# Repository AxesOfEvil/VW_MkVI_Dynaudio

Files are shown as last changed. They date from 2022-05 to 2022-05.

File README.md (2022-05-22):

# Dynaudio Amplifier control for VW MkVI GTI

The MkVI Volkswagen GTI uses CAN bus commands to power on/off as well as
for fade/balance settings

This means that an aftermarket head-unit may not be able to power-on the
amplifier, and thus no sound will be heard.

This project addresses this issue by sending the appropriate power on/off 
commands to the Stock Dynaudio amplifier when the 'Amp Power' wire has
12V on it (alternately, attach the common 'Accessory' wire if the head-unit
has no 'Amp Power' wire)

# How it works
The cirucit uses a self-latching power circuit for low-power operation.
When 12V is detected on the 'Amp Power' wire, the circuit will power up.
The Arduino will then keep the circuit powered even if 'Amp Power' is turned
off.

When the Arduino detects the 'Amp Power' at 12V, it will send the Dynaudio
amplifier the power up signals via the CAN bus, and go to sleep.

When the 'Amp Power' wire drops to 0V, the Arduino will wakeup, send the
power-down sequence to the Dynaudio amplifier, and then turn itself off.
Once off, the only way to power up the Arduino again is to apply 12V to the
'Amp Power' wire.

# About the schematic
An AVR based arduino is used because of its 5V tolerance. Specifically,
either a 'Pro Micro' or 'Pro Mini' Arduino is recommended.  It should not
matter if the Arduino board is a 5V or 3.3V variant (both are capable of being
powered at 5V).

The LDO can be replaced with a DC/DC supply to further reduce current, though
the difference is only ~100mW of power (when active, the circuit consumes
negligible power when the 'Power Amp' wire is inactive)

I prefered to use an Arduino 'Pro Micro' instead of the 'Pro Mini' primarily
because it has a USB interface that could be used in the future to control
additional CAN bus functions.  However, the 'Pro Micro' uses USB programming
which does not play very nicely with the low-power states used by software.
When using a 'Pro Micro' it is recommended, to flash the 'Optiboot' firmware
such that the board can be programmed via Serial1 instead of via USB.

# Building the software
The software uses the following Arduino libraries:

* `Arduino-MCP2515` : https://github.com/autowp/arduino-mcp2515
* `Low Power`

# CAN bus protocol
The Dynaudio amplifier listens on interface 0x6C7 for amplifier commands.
As the commands were snooped from a working head-unit, their individual
function is not fully known.

Power up seems to require a minimum of 5 frames, with the 1st byte being
0x1B or 0x2B.  After power-on, and additional 13 frames are sent to set the
fade/balance/etc settings, but the meaning of these frames is not yet known.

Power-down requires only a single frame (with 1st byte = 0x2b)

# VW Media Can bys data (100kbps)

| Identifier | Data | Description |
| ---| --- | --- |
| 0x5C1 | 06 00 00 60 | vol up (repeats periodically while button is held) |
| 0x5C1 | 07 00 00 60 | vol down (repeats periodically while button is held) |
| 0x5C1 | 03 00 00 60 | left button (repeats periodically while button is held) |
| 0x5C1 | 02 00 00 60 | right button (repeats periodically while button is held) |
| 0x5C1 | 2A 00 00 60 | mic button (repeats periodically while button is held) |
| 0x5C1 | 1A 00 00 60 | phone button (repeats periodically while button is held) |
| 0x5C1 | 29 00 00 60 | return button (repeats periodically while button is held) |
| ---------- | ----------------------- | ----------- |
| 0x6C7 | 80 04 2B 57 00 05 01 xx | Dynaudio amp left/right fade (8-bit signed int. 0x80 = full left, 0x7f = full right |
| 0x6C7 | 80 04 2B 58 00 05 01 xx | Dynaudio amp front/back balance (8-bit signed int. 0x80 = full back, 0x7f = full front |
| 0x6C7 | 2B 50 00 | Dynaudio amp power down |
| 0x6C7 | 1B 42 | Dynaudio amp ??? (powerup frame 1) |
| 0x6C7 | 1B 43 | Dynaudio amp ??? (powerup frame 2) |
| 0x6C7 | 1B 41 | Dynaudio amp ??? (powerup frame 3) |
| 0x6C7 | 2B 50 01 | Dynaudio amp ??? (powerup frame 4) - power up ? |
| 0x6C7 | 2B 53 00 | Dynaudio amp ??? (powerup frame 5) |
| 0x6C7 | 80 07 2B 55 78 00 00 00 | Dynaudio amp ??? (powerup frame 6) - resent periodically |
| 0x6C7 | C0 22 22 00 | Dynaudio amp ??? (powerup frame 7) - resent periodically |
| 0x6C7 | 80 07 2B 51 00 00 04 05 | Dynaudio amp ??? (powerup frame 8) |
| 0x6C7 | C0 0A 08 FF | Dynaudio amp ??? (powerup frame 9) |
| 0x6C7 | 80 03 1B 52 00 00 0D | Dynaudio amp ??? (powerup frame 10) |
| 0x6C7 | 80 03 1B 54 00 00 0D | Dynaudio amp ??? (powerup frame 11) |
| 0x6C7 | 80 03 1B 57 00 00 0D | Dynaudio amp ??? (powerup frame 12) |
| 0x6C7 | 80 03 1B 58 00 00 0D | Dynaudio amp ??? (powerup frame 13) |
| 0x6C7 | 80 03 1B 59 00 00 0D | Dynaudio amp ??? (powerup frame 14) |
| 0x6C7 | 80 03 1B 5A 00 00 0D | Dynaudio amp ??? (powerup frame 15) |
| 0x6C7 | 80 03 1B 5B 00 00 0D | Dynaudio amp ??? (powerup frame 16) |
| 0x6C7 | 80 03 1B 5C 00 00 04 | Dynaudio amp ??? (powerup frame 17) |
| 0x6C7 | 80 03 1B 5E 00 00 04 | Dynaudio amp ??? (powerup frame 18) |
| ---------- | ----------------------- | The following data was collected by hugovw1976 (see link below) |
| 0x2C3 | aa | aa: bit0 power on |
| 0x635 | aa bb cc | aa: bit0 lights on |
| 0x466 | aa bb cc dd ee ff gg hh | bb: door-open - bit0: driver, bit1: passenger, bit2: rear-driver, bit3: rear passenger, bit4: hood, bit5: trunk |
| 0x35B | aa bb cc dd ee ff gg hh | ccbb: RPM*4 (unconfirmed) |
| 0x527 | aa bb cc dd ee ff gg hh | ccbb: Speed (units?) (unconfirmed), ff: (outside temperature(C) +50)/2 |
| 0x621 | aa bb cc dd ee ff gg | aa: bit 2: wiper state, dd: fuel level (liters) (bit 7 is set to indicate low-fuel when <10l) |
| 0x65D | aa bb cc dd ee ff gg hh | ddeecc: odometer (unconfirmed) |
| 0x351 | aa bb cc dd ee ff gg hh | aa: bit0: reverse (unconfirmed), cc: bit0: brake (unconfirmed)|
| 0x571 | aa bb cc dd ee ff | aa: (battery voltage * 10 + 50) / 2 |
| 0x151 | aa bb cc dd | bb: seat-belt (unconfirmed) |

# Additional Resources
* Using a Raspberry Pi to snoop the CAN bus with a $3 Ebay MCP2515
  * This modification allows running the SPI interface at 3.3V while running
    the CAN interface at 5V: https://forums.raspberrypi.com/viewtopic.php?t=141052
  * Savvy CANbus GUI: https://www.savvycan.com/

* Pinout for VW MkBI head unit
  * https://pinoutguide.com/Car-Stereo-Volkswagen-Porsche/Volkswagen_RCD_310_Head_U_pinout.shtml
  * https://connector.pinoutguide.com/40__16_12_12__pin_Head_Unit_Car_Stereo_Quadlock/

* Interesting articles on CAN bus hacking
  * General overview: https://theksmith.com/software/hack-vehicle-bus-cheap-easy-part-2/
  * Analyzing a VW Gauge cluster using CAN bus hacking (also shows how to use
    the 'savvy' CAN bus analyzer GUI: https://www.youtube.com/watch?v=GOuglqFtmOE&t=23s
  * CANid database for various vendors: https://github.com/iDoka/awesome-automotive-can-id
  * DTB files for CANids for various vendors: https://github.com/commaai/opendbc
  * XDA posting by hugovw1976 with some Golf6 Canids: https://forum.xda-developers.com/t/mtcd-kgl-px5-canbus-problem-with-vw-golf-6.3632690/post-73939457

* Installing Optiboot on Pro Micro
  * NOTE: The official Optiboot github repo supports the Atmega32U4 now.
    https://www.instructables.com/How-to-upload-sketches-to-Pro-MicroLeonardo-via-se/
  * Optiboot home: https://github.com/Optiboot/optiboot/wiki

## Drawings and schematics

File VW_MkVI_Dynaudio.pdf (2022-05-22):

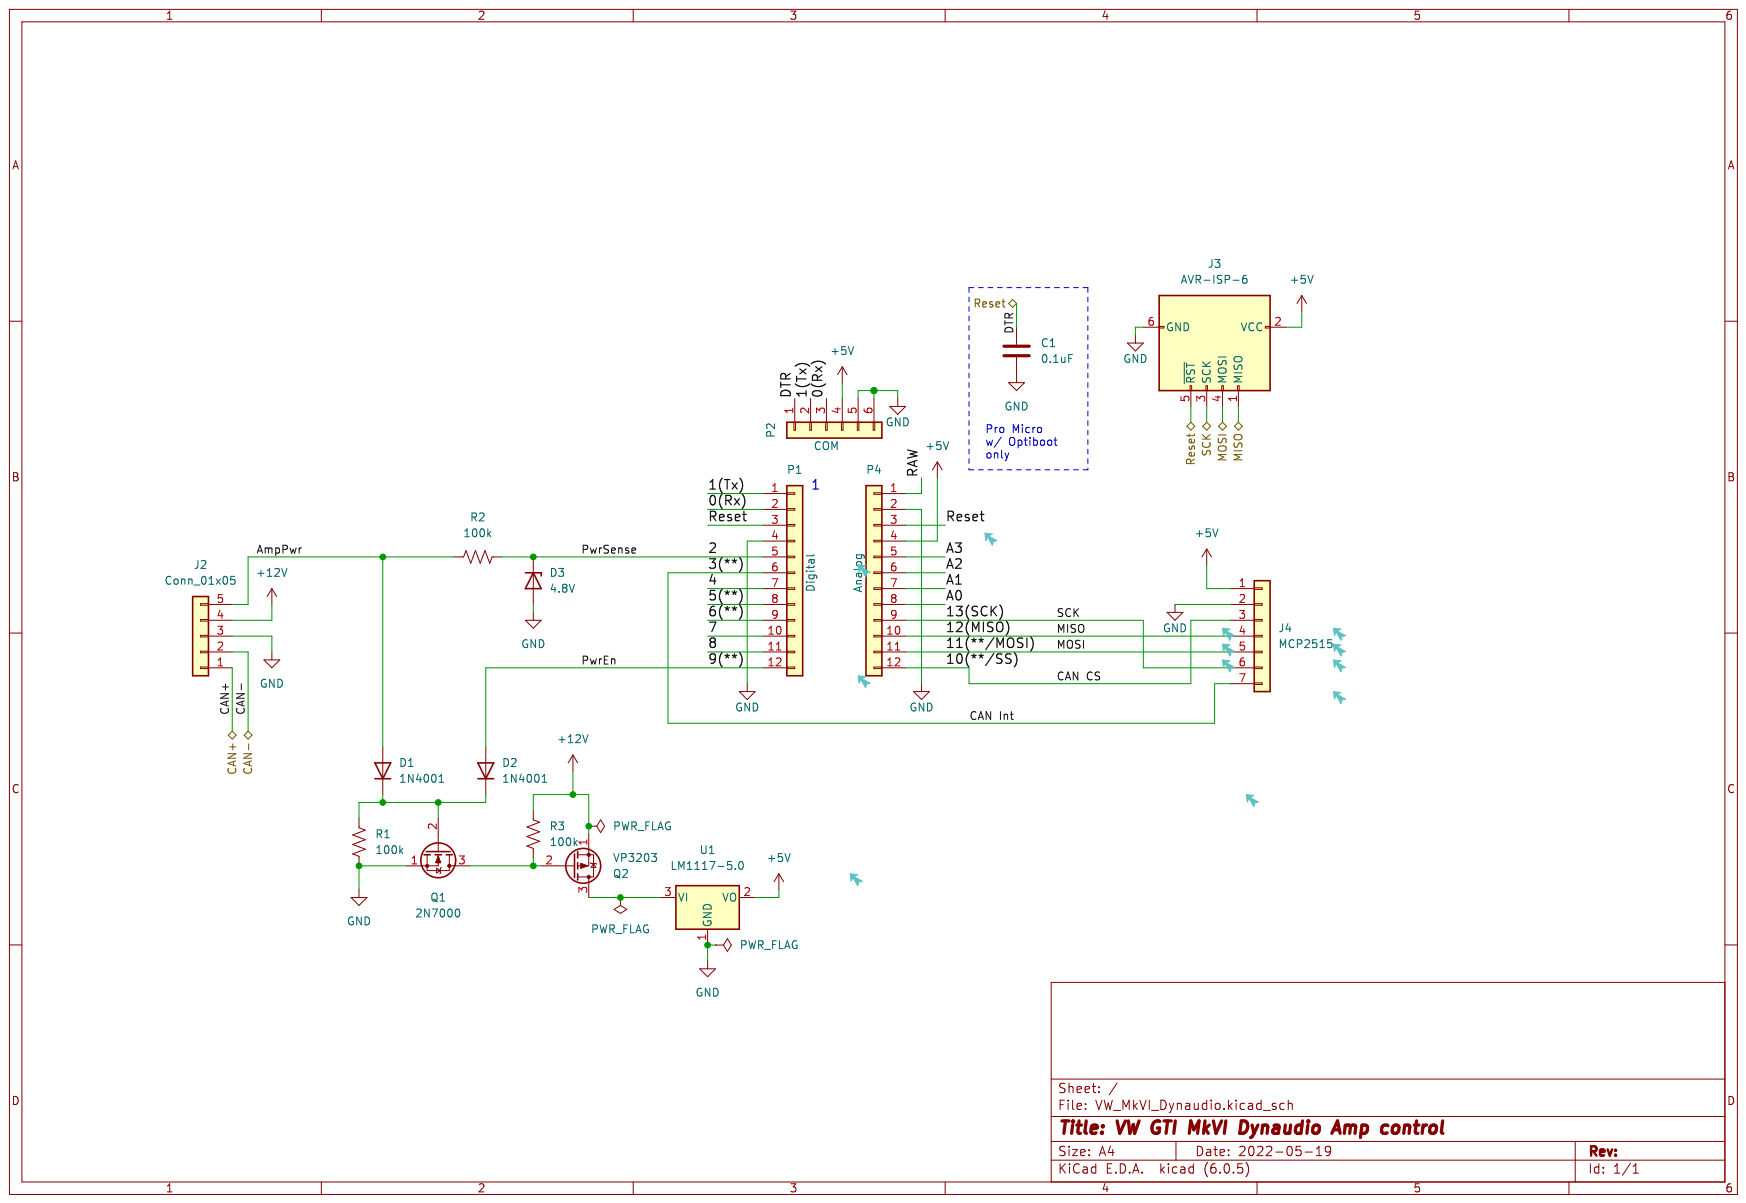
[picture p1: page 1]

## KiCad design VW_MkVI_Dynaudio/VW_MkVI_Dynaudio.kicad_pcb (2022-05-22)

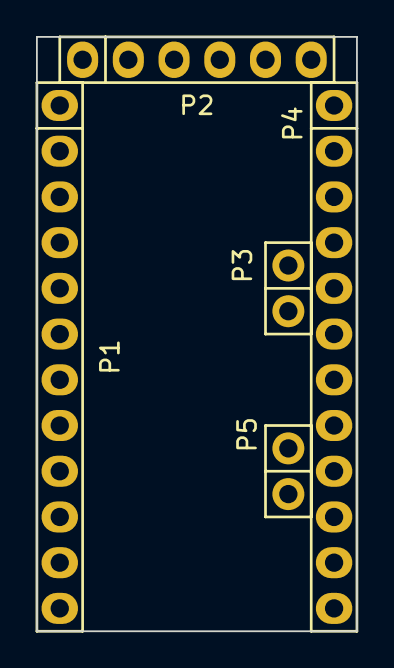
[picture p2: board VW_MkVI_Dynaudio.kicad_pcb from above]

Board: 2 copper layers, 17.8 x 33.0 mm, 5 parts (0 on the bottom side), 5 nets, no tracks yet.

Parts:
P1: Digital; Socket_Strip_Arduino_1x12
P2: COM; Socket_Strip_Arduino_1x06
P3, P5: ADC; Socket_Strip_Arduino_1x02
P4: Analog; Socket_Strip_Arduino_1x12

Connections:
/0(Rx): P1.2, P2.3
/1(Tx): P1.1, P2.2
/Reset: P1.3, P4.3
GND: P1.4, P2.5, P2.6, P4.2
VCC: P2.4, P4.4

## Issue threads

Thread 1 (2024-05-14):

Trying to simulate ignition

veso266, 2024-05-14:
Hello there
I have a test bench for PQ platform which you can see on the picture: https://imgur.com/fyGPqXu

On my Bench is RNS510 and 3C0 907 530 L gateway module

I would like to simulate ignition message
I use MCP2515 module with my Arduino (seerduino the only difference is that u can also put it on 3.3V operation instead of 5V)

I also discovered that VW PQ cars have 3 canbuses: https://imgur.com/a/FAXZZzY
Infotaiment - 100kbps
Conveniences - 100kbps
Drive train - 500kbps

I was able to throw together this little test program to trying to simulate ignition message
I tried to use this library: https://github.com/autowp/arduino-mcp2515/tree/master
```c
#include <SPI.h>
#include "mcp25151.h"

//MCP_CAN CAN0(10);     // Set CS to pin 10
MCP2515 mcp2515(10); // Set CS to pin 10

struct can_frame canMsg;

void sendCAN(uint32_t id, uint8_t length, uint8_t data0 = 0x00 , uint8_t data1 = 0x00 , uint8_t data2 = 0x00 , uint8_t data3 = 0x00 , uint8_t data4 = 0x00 , uint8_t data5 = 0x00 , uint8_t data6 = 0x00 , uint8_t data7 = 0x00);

void setup() {
  Serial.begin(115200);

  // Initialize MCP2515 running at 8MHz with a baudrate of 100kb/s and the masks and filters disabled.
  //if(CAN0.begin(MCP_ANY, CAN_500KBPS, MCP_8MHZ) == CAN_OK) Serial.println("MCP2515 Initialized Successfully!");
  //else Serial.println("Error Initializing MCP2515...");

  //CAN0.setMode(MCP_NORMAL);   // Change to normal mode to allow messages to be transmitted

  Serial.println("SetBitrate: " + String(mcp2515.setBitrate(CAN_500KBPS, MCP_8MHZ)));
  Serial.println("SetMode: " + String(mcp2515.setNormalMode()));
  Serial.println("VW CAN Interface");

}

void loop() {
  sendCAN(0x271, 2, 0x01, 0x80); //Ignition on

  //3 bytes 1. byte hat 0 wenn licht aus und 0x5C wenn licht an
  sendCAN(0x635, 3, 0x00, 0xFF, 0x00); //Light on

//7 bytes 1st byte bit 1 reverse gear
  //sendCAN(0x351, 7, 0x00, 0x01, 0x00, 0x02, 0x00, 0x00, 0x7E, 0x7E); //Car is in reverse

  delay(100);

}

void sendCAN(uint32_t id, uint8_t length, uint8_t data0 , uint8_t data1 , uint8_t data2 , uint8_t data3 , uint8_t data4 , uint8_t data5 , uint8_t data6 , uint8_t data7) {
  struct can_frame canMsg1;
  canMsg1.can_id  = id;
  canMsg1.can_dlc = length;
  canMsg1.data[0] = data0;
  canMsg1.data[1] = data1;
  canMsg1.data[2] = data2;
  canMsg1.data[3] = data3;
  canMsg1.data[4] = data4;
  canMsg1.data[5] = data5;
  canMsg1.data[6] = data6;
  canMsg1.data[7] = data7;
  mcp2515.sendMessage(MCP2515::TXB1, &canMsg1);
}

The problem is that nothing happens
If I disconnect the gateway, connect to 100kbps inforaiment bus according to this gateway pinout
```
1,2 - +12v (connection 30)
14 - +12v (connection 15 [Ignition])
11,12 - Ground connection
6 - powertrain CAN bus, low
16 - powertrain CAN bus, high
9 - DIAGNOSE can low
19 - DIAGNOSE can high
8 - Dashboard can low
18 - Dashboard can high
5 - convenience CAN bus, low
15 - convenience CAN bus, high
10 - infotainment CAN bus, low
20 - infotainment CAN bus, high
13 - to Dashboard pin15
```

my radio (RNS510 is not happy: https://imgur.com/B4BlY3l)
if gateway is connected, this is what RNS510 displays: https://imgur.com/PAH2PBI

The problem is that I have no acsess to any PQ vehicle anymore so I don't have any real data so maybe am I not generating a proper message or my wiring is not correct, I don't know

So I would like to try to come to a common denominator, like SW is OK, my Hardware is faulty, so I was wondering if you maybe have some example code that would simulate ignition or turn lights on your radio on and you know that it does work so I could be sure, ok, this code should generate a proper walkup message and my hardware/connnections is not OK

BTW: if I connect to a drive train (500kbps bus), I can clearly see proper messages
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

so maybe I just am not generating a proper walkup signal or my timings are not correct, idk

Thanks for Anwsering and Best Regards

AxesOfEvil, 2024-05-14:
I don't think I have exactly what you are looking for, but here are various codes captured from my vehicle.  many of them are related to pressing buttons on the steering wheel (5x means I pressed it 5 times).
I think the powerup/powerdown are turning on/off the amp, but I'm not 100% sure.  They could be ignition on/off or radio on/off
the 1 and 2 are just long captures which may or may not have me changing random things.
This data is all a couple years old, so I don't remember the details of what I was capturing.

[can.tar.gz](https://github.com/AxesOfEvil/VW_MkVI_Dynaudio/files/15313544/can.tar.gz)

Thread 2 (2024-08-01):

Aux Mode Keeps AMP power always ON

MattDGTL, 2024-08-01:
When the radio is on AUX mode, it keeps the amp power on no matter what. I currently have the OEM RNS 315 in my trunk on AUX mode while I have an Android Head Unit on my dash and everything works perfect, only problem is I have to power on the OEM radio in the trunk manually every time I start the car.. if you can read the canbus AMP on code from AUX maybe that'll work better.

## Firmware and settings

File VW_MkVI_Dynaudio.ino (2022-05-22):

#include <SPI.h>
#include <mcp2515.h>
#include <avr/sleep.h>//this AVR library contains the methods that controls the sleep modes
#include <LowPower.h>
#include "CanMsg.h"

MCP2515 mcp2515(10); //Use Pins: CS=10, SCK=14, MISO=15, MOSI=16
#define wakePin 2
#define pwrPin 9
#define canIntPin 3
#define RXLED 17
#define Ser if(0) Serial1

enum {
  STATE_INIT = 0,
  STATE_POWERUP,
  STATE_POWERDOWN,
  STATE_UNKNOWN,
};

int led = 0;
int change = 0;

void set_led(bool state) {
  led = state;
  digitalWrite(RXLED, state ? LOW : HIGH);
}

void flash_led(int count, int led_delay=50){
  int orig_led = led;
  if (led) {
    set_led(0);
    delay(led_delay);
  }
  for (int i = 0; i < count; i++) {
    set_led(1);
    delay(led_delay);
    set_led(0);
    delay(led_delay);
  }
  if (orig_led) {
    set_led(1);
  }
}

void GoingToSleep(){
    Ser.println("going to sleep!");
    sleep_enable();//Enabling sleep mode
    //attachInterrupt(digitalPinToInterrupt(wakePin), wakeUp, LOW);//attaching a interrupt to pin d2
    set_sleep_mode(SLEEP_MODE_PWR_DOWN);//Setting the sleep mode, in our case full sleep
    sleep_cpu();//activating sleep mode
    Ser.println("just woke up!");//next line of code executed after the interrupt 
  }

void wakeUp(){
  Ser.println("Interrrupt Fired");//Print message to serial monitor
  sleep_disable();//Disable sleep mode
  detachInterrupt(digitalPinToInterrupt(wakePin)); //Removes the interrupt from pin 2;
}

void wake2(){
  sleep_disable();
  change = digitalRead(wakePin) ? 4 : 2;
  detachInterrupt(digitalPinToInterrupt(wakePin));
}
void setup() {  
  pinMode(pwrPin,OUTPUT);
  digitalWrite(pwrPin, HIGH);
  
  //while (!Serial);
  Ser.begin(115200);
  
  mcp2515.reset();
  mcp2515.setBitrate(CAN_100KBPS, MCP_8MHZ);
  mcp2515.setNormalMode();
  pinMode(wakePin,INPUT);  //PUSH/PULL
  pinMode(RXLED, OUTPUT);
  pinMode(canIntPin, INPUT_PULLUP);
  flash_led(3);
  Ser.println("Example: Write to CAN");
  //attachInterrupt(digitalPinToInterrupt(wakePin), wake2, CHANGE);
}


void ampPowerUp() {
  for (int i = 0; i < sizeof(canMsg_AmpEnable) / sizeof(can_frame); i++) {
    mcp2515.sendMessage(&canMsg_AmpEnable[i]);
    delay(50);  
  }
  set_led(1);
  Ser.println("PowerUp");
}

void ampPowerDown() {
  mcp2515.sendMessage(&canMsg_AmpDisable);
  set_led(0);
  Ser.println("PowerDown");
}

void loop() {
  static int state = STATE_INIT;
  Ser.println("loop");
  if (state == STATE_INIT) {
    delay(500);  // Ensure rail reaches 5V
    ampPowerUp();
    delay(1000);  // Debounce for paranoia
    state = STATE_POWERUP;
    return;
  }
  int updn = digitalRead(wakePin);
  Ser.print("Up/Down: ");
  Ser.println(updn);
  if (updn) {
    if (state == STATE_POWERDOWN) {
      digitalWrite(pwrPin, HIGH);
      ampPowerUp();
      state = STATE_POWERUP;
      delay(1000);
    }
  } else {
    if (state == STATE_POWERUP) {
      set_led(0);
      delay(10);
      set_led(1);
      ampPowerDown();
      state = STATE_POWERDOWN;
      delay(1000);
      digitalWrite(pwrPin, LOW);
    }
  }
  LowPower.powerDown(SLEEP_1S, ADC_OFF, BOD_OFF); 
  //LowPower.idle(SLEEP_1S, ADC_OFF, TIMER4_OFF, TIMER3_OFF, TIMER1_OFF, TIMER0_OFF, 
  //              SPI_OFF, USART1_OFF, TWI_OFF, USB_OFF);

}

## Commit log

2022-05-22 Initial version
    [VW_MkVI_Dynaudio.kicad_pcb, VW_MkVI_Dynaudio.kicad_sch]
2022-05-22 Add button canid messages
